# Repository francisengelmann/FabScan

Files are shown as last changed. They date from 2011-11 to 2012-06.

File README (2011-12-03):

FabScan - Affordable 3D Laser Scanning of Physical Objects

Visit http://hci.rwth-aachen.de/fabscan for presentation and documentation about the project.

FabScan makes use of the OpenCV and PCL (Point Cloud Library). See http://pointclouds.org/downloads/ for installation instructions.
For development on the Mac, just install Homebrew (http://mxcl.github.com/homebrew/) and type 'brew install opencv'.

Folder Structure:

-> arduino :: contains the firmware for the Arduino inside the FabScanner
-> experimental
  -> pointclouds :: sample pointclouds created with the FabScan
  -> PCL :: contains example code from the Point Cloud Library
-> parts :: contains all the models for the hardware
-> sources :: source code of FabScan software

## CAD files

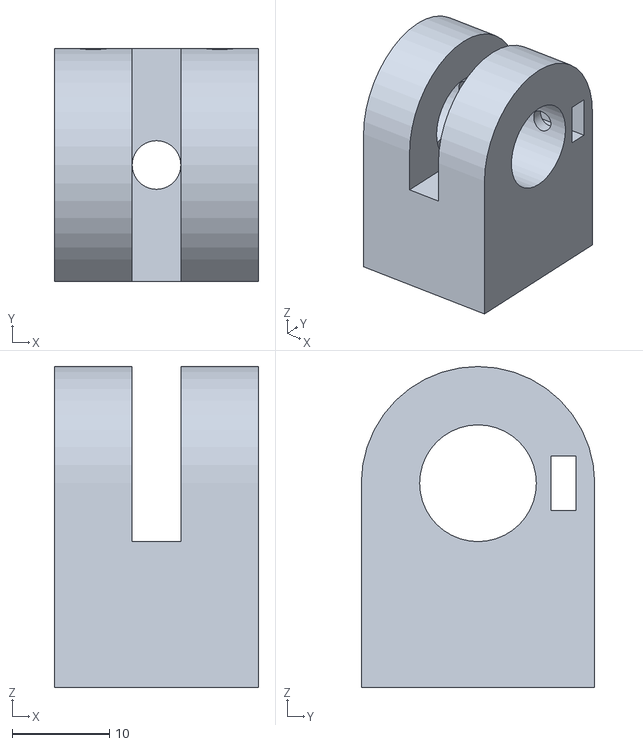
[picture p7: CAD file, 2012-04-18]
parts/LaserHolder2.stl
21.0 x 24.0 x 33.0

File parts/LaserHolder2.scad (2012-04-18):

$fn = 40; //change this to make the edges more round! Rendering will become slower.

lhIR = 6; //this is where you define the radius of your laser module!
lhOR = lhIR+6; 
lhH = 8;

shIR = 2.5;
shXS = shIR+2*lhH;
shYS = 2*lhOR;
shZS = 15;

nutY = 2.6;
nutZ = 5.6;

module screw(){
	rotate([-90,0,0])
	cylinder(h=25, r=1.5);
}

//breit: 5.4mm
//hoch: 2.3mm
module nut(){
	scale([25, nutY, nutZ])
	cube();
}

module laserHolder(){
	difference(){
		union(){
			rotate([0,90,0])
			cylinder(h=lhH, r=lhOR);
			translate([0,-lhOR,-(shZS+lhIR)])
			scale([lhH,2*lhOR,shZS+lhIR])
			cube(1);
		}
		rotate([0,90,0])
		translate([0,0,-1])
		cylinder(h=lhH+2, r=lhIR);
		translate([-2,(lhIR+lhOR)/2-1.5,-nutZ/2])
		nut();
		translate([lhH/2,0,0])
		screw();
	}
}

module stepperHolder(){
	difference(){
		translate([-shXS/2, -shYS/2])
		scale([shXS, shYS, shZS])
		cube(1);
		translate([0,0,-1])
		cylinder(h=shZS+2, r=shIR);	
	}
}

module complete(){
	difference(){
		union(){
			translate([0,0,lhIR+shZS]){
				translate([-lhH-shIR,0,0])
				laserHolder();
				translate([shIR,0,0])
				laserHolder();
			}
			stepperHolder();
		}
		rotate([0,0,90])
		translate([0,0,5])
		screw();
		rotate([90,90,0])
		translate([-3*nutZ,-7.5,-nutZ/2])
		nut();
	}
}

//laserHolder();
//stepperHolder();
complete();

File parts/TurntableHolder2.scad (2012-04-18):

$fn = 40;

r_motorSchaft = 2.5;
l_motorSchaft = 21;

r_aussparung = 10;
l_aussparung = 8;

r_Stange = 7.85/2;
l_Stange = 22.5;


//Schlitz 5.4 x 2.5

d_teller = 40;

dist_schrauben = d_teller/2;


module anMotor()
{
	difference()
	{
		cylinder( h=l_aussparung, r=r_aussparung);
		translate(v=[0,0,-1]) cylinder(h=l_motorSchaft, r=r_motorSchaft);
		translate(v=[-r_aussparung-0.5,0,4.8]) rotate(a=[0,90,0]) cylinder(h=r_aussparung*2+1, r=1.5);

		translate(v=[-r_aussparung+3.5,0-5.4/2,6+5.4/2]) rotate(a=[0,90,0]) scale([9.2, 5.4, 2.5]) cube(1);//Mutter
		translate(v=[r_aussparung-6,0-5.4/2,6+5.4/2]) rotate(a=[0,90,0]) scale([9.2, 5.4, 2.5]) cube(1);//Mutter



	}
}


module M3Schraube()
{
	translate([0,0,-3])
	{
		union()
		{
			cylinder(h=l_aussparung+9, r=1.5);

			//translate([0,0,l_aussparung+9]) cylinder(h=3.3, r=5.5/2);//dickerer Kopf für Senke
			translate([0,0,l_aussparung+9])  cylinder(h=l_aussparung+9, r=1.5);//da wir erstmal nur kleben wollen sparen wir hier stützmaterial
		}
	}

}

module rundung()
{
		union()
		{
		for ( i = [0 : 90] )
		{
			translate([0,0,l_aussparung+ i*0.1]) cylinder(h=0.1, r=r_aussparung + 2* sin(i)*d_teller/4);
		}
		}
}

module anStange()
{
	difference()
	{
		rundung();

		union()
		{
			translate(v=[0,0,-1]) cylinder(h=l_motorSchaft, r=r_motorSchaft);
			translate([dist_schrauben, 0, 0]){ M3Schraube(); translate([-3.0,-3.0,6.0]) scale([6.0, 6.0, 6.0]) cube(1);}
			translate([-dist_schrauben, 0, 0]){ M3Schraube();translate([-3.0,-3.0,6.0]) scale([6.0, 6.0, 6.0]) cube(1);}
			translate([0, dist_schrauben, 0]){ M3Schraube();translate([-3.0,-3.0,6.0]) scale([6.0, 6.0, 6.0]) cube(1);}
			translate([0, -dist_schrauben, 0]){ M3Schraube();translate([-3.0,-3.0,6.0]) scale([6.0, 6.0, 6.0]) cube(1);}
		}

	}
}


module sparbox()
{
	translate([0,5,l_aussparung+4]) scale([8,16,15]) cube(1, center=true);
}

module materialsparen()
{
union()
{
translate([-10,10,0]) rotate(45)  sparbox();
translate([17,17,0]) rotate(135)  sparbox();
translate([17,-17,0]) rotate(45)  sparbox();
translate([-10,-10,0]) rotate(135)  sparbox();
}
}


module kupplung()
{
	union()
	{
		anMotor();
		anStange();
	}
}

difference()
{
kupplung();
materialsparen();
}

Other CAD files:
experimental/pointclouds/whiteCup2/whiteCup.ply

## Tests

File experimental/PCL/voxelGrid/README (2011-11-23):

Downsampling a PointCloud using a VoxelGrid filter
==================================================
see http://pointclouds.org/documentation/tutorials/voxel_grid.php

Compiling the example
=====================
To compile and run the code, follow these steps:

mkdir build
cd build
cmake ..

Now the mafile should be there. Type this:

make
./voxel_grid

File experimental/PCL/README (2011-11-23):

Make sure you have cmake installed.

Installing PCL
==============
Linux:
	see http://pointclouds.org/downloads/linux.html

Mac: download and install Homebrew (http://mxcl.github.com/homebrew/)
	In Terminal type: brew install pcl

For more detailed information please check: http://pointclouds.org/downloads/

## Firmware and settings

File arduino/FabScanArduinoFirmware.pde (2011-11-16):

// FabScan - http://hci.rwth-aachen.de/fabscan
//
//  Created by Francis Engelmann on 7/1/11.
//  Copyright 2011 Media Computing Group, RWTH Aachen University. All rights reserved.

#define LED_PIN 14
#define LIGHT_PIN 11
#define LASER_PIN 5

#define ENABLE_PIN_0  6
#define RESET_PIN_0   7
#define SLEEP_PIN_0   8
#define STEP_PIN_0    9
#define DIR_PIN_0     10

#define ENABLE_PIN_1  3
#define RESET_PIN_1   2
#define SLEEP_PIN_1   4
#define STEP_PIN_1    13
#define DIR_PIN_1     12
  
#define TURN_LASER_OFF      200
#define TURN_LASER_ON       201
#define PERFORM_STEP        202
#define SET_DIRECTION_CW    203
#define SET_DIRECTION_CCW   204
#define TURN_STEPPER_ON     205
#define TURN_STEPPER_OFF    206
#define TURN_LIGHT_ON       207
#define TURN_LIGHT_OFF      208
#define ROTATE_LASER        209
#define FABSCAN_PING        210
#define FABSCAN_PONG        211
#define SELECT_STEPPER      212

//the protocol: we send one byte to define the action what to do.
//If the action is unary (like turnung off the light) we only need one byte so we are fine.
//If we want to tell the stepper to turn, a second byte is used to specify the number of steps.
//These second bytes are defined here below.

#define ACTION_BYTE         1    //normal byte, first of new action
#define LIGHT_INTENSITY     2
#define TURN_TABLE_STEPS    3
#define LASER1_STEPS        4
#define LASER2_STEPS        5
#define LASER_ROTATION      6
#define STEPPER_ID          7

int incomingByte = 0;
int byteType = 1;
int currStepper;

void step()
{
 digitalWrite(LED_PIN, 0);
 
 if(currStepper == 0){
   digitalWrite(STEP_PIN_0, 0);
 }else if(currStepper == 1){
   digitalWrite(STEP_PIN_1, 0);
 }

 delay(3);
 if(currStepper == 0){
   digitalWrite(STEP_PIN_0, 1);
 }else if(currStepper == 1){
   digitalWrite(STEP_PIN_1, 1);
 }
 digitalWrite(LED_PIN, 1);
 delay(3);
}

void step(int count)
{
  for(int i=0; i<count; i++){
    step();
  }
}

void setup() 
{ 
  // initialize the serial port
  Serial.begin(9600);
 pinMode(LASER_PIN, OUTPUT);
 pinMode(LIGHT_PIN, OUTPUT);
 pinMode(LED_PIN, OUTPUT);
 
 pinMode(ENABLE_PIN_1, OUTPUT);
 pinMode(RESET_PIN_1, OUTPUT);
 pinMode(SLEEP_PIN_1, OUTPUT);
 pinMode(DIR_PIN_1, OUTPUT);
 pinMode(STEP_PIN_1, OUTPUT);
 
 pinMode(ENABLE_PIN_0, OUTPUT);
 pinMode(RESET_PIN_0, OUTPUT);
 pinMode(SLEEP_PIN_0, OUTPUT);
 pinMode(DIR_PIN_0, OUTPUT);
 pinMode(STEP_PIN_0, OUTPUT);
  
 digitalWrite(RESET_PIN_0, HIGH);  //HIGH to turn
 digitalWrite(SLEEP_PIN_0, HIGH);  //HIGH to turn
 digitalWrite(ENABLE_PIN_0, HIGH);  //LOW to turn
  
 digitalWrite(RESET_PIN_1, HIGH);  //HIGH to turn
 digitalWrite(SLEEP_PIN_1, HIGH);  //HIGH to turn
 digitalWrite(ENABLE_PIN_1, HIGH);  //LOW to turn
 
 digitalWrite(LIGHT_PIN, 1); //turn light on

 digitalWrite(LASER_PIN, 1); //turn laser on
 Serial.write(FABSCAN_PONG); //send a pong back to the computer so we know setup is done and that we are actually dealing with a FabScan
 
 currStepper = 0;  //turntable is default stepper
} 

void loop() 
{
  digitalWrite(LED_PIN, 0);
  if(Serial.available() > 0){
    digitalWrite(LED_PIN, 1);
    incomingByte = Serial.read();
    
    switch(byteType){
      case ACTION_BYTE:
      
          switch(incomingByte){    //this switch always handles the first byte
            //Laser
            case TURN_LASER_OFF:
              digitalWrite(LASER_PIN, LOW);    // turn the LASER off
              break;
            case TURN_LASER_ON:
              digitalWrite(LASER_PIN, HIGH);   // turn the LASER on
              break;
            case ROTATE_LASER: //unused
              byteType = LASER_ROTATION;
              break;
            //TurnTable
            case PERFORM_STEP:
              byteType = TURN_TABLE_STEPS;
              break;
            case SET_DIRECTION_CW:
              if(currStepper == 0){
                digitalWrite(DIR_PIN_0, 1);
              }else if(currStepper == 1){
                digitalWrite(DIR_PIN_1, 1);
              }
              break;
            case SET_DIRECTION_CCW:
              if(currStepper == 0){
                digitalWrite(DIR_PIN_0, 0);
              }else if(currStepper == 1){
                digitalWrite(DIR_PIN_1, 0);
              }
              break;
            case TURN_STEPPER_ON:
              if(currStepper == 0){
                digitalWrite(ENABLE_PIN_0, 0);
              }else if(currStepper == 1){
                digitalWrite(ENABLE_PIN_1, 0);
              }
              break;
            case TURN_STEPPER_OFF:
              if(currStepper == 0){
                digitalWrite(ENABLE_PIN_0, 1);
              }else if(currStepper == 1){
                digitalWrite(ENABLE_PIN_1, 1);
              }
              break;
            case TURN_LIGHT_ON:
              byteType = LIGHT_INTENSITY;
              break;
            case TURN_LIGHT_OFF:
              digitalWrite(LIGHT_PIN, 0);
              break;
            case FABSCAN_PING:
              delay(1);
              Serial.write(FABSCAN_PONG);
              break;
            case SELECT_STEPPER:
              byteType = STEPPER_ID;
              break;
            }
      
          break;
       case LIGHT_INTENSITY:       //after this point we take care of the second byte if one is sent
          analogWrite(LIGHT_PIN, incomingByte);
          byteType = ACTION_BYTE;  //reset byteType
          break;
        case TURN_TABLE_STEPS:
          step(incomingByte);
          byteType = ACTION_BYTE;
          break;
        case STEPPER_ID:
          currStepper = incomingByte;
          byteType = ACTION_BYTE;
          break;
    }
  } 
} 

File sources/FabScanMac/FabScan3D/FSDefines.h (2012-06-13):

//
//  FSDefines.h
//  FabScan3D
//
//  Created by Francis Engelmann on 7/18/11.
//  Copyright 2011 Media Computing Group, RWTH Aachen University. All rights reserved.
//

//zero point of laser in model is perpendicular to the chessboard plane
//the offset_angle is the angle between the perpendicular and the actual laser line
#define LASER_OFFSET_ANGLE 0.0f
#define DELAY_UNTIL_CAM_SHOT 500000

//#define DPI_HORIZONTAL 10.0f
//#define DPI_VERTICAL 2.0f

/**
 * The following lines define the "protocol" for communication
 * between the computer and the microcontroller (MC) over the serial port.
 * Every byte stands for a operation.
 * All the values below 200 are reserved to position the servo, but servo sucks so this will be replaced and is not valid anymore
 * For 200-255 see below.
 */

#define MC_TURN_LASER_OFF      200
#define MC_TURN_LASER_ON       201
#define MC_PERFORM_STEP        202
#define MC_SET_DIRECTION_CW    203
#define MC_SET_DIRECTION_CCW   204
#define MC_TURN_STEPPER_ON     205
#define MC_TURN_STEPPER_OFF    206
#define MC_TURN_LIGHT_ON       207
#define MC_TURN_LIGHT_OFF      208
#define MC_ROTATE_LASER        209
#define MC_FABSCAN_PING        210
#define MC_FABSCAN_PONG        211
#define MC_SELECT_STEPPER      212

#define REALLY_BIG_NUMBER     99999
#define REALLY_SMALL_NUMBER  -99999

#define YES 1
#define NO  0

//treshold for substracting the laser frame from the non laser frame
#define TRESHOLD_FOR_BW 100 //70

#define STEPPER_ID_TURNTABLE  0
#define STEPPER_ID_LASER      1 

//to make the scanning process faster we ommit the lower and hight part of the cvImage
//as there is no object anyway.  The lower limit is defined by the turning table lower bound
//units are pixels, seen from the top, resp from the bottom

#define UPPER_ANALYZING_FRAME_LIMIT 250
#define LOWER_ANALYZING_FRAME_LIMIT 30

//as the actual position in the frame differs a little from calculated laserline we stop a little befor as we might catch the real non reflected laser line which creates noise
#define ANALYZING_LASER_OFFSET 100


//defining the origin in the cvFrame
//the position of intersection of back plane with ground plane in cvFrame in procent
//check the yellow laser line to calibrate, the yellow laser line should touch the bottom plane
//#define ORIGIN_Y 0.725
#define ORIGIN_Y 0.825

//the angle used to scan, obsolete when the laser is also moving
#define SCANNING_ANGLE 33.69f//33.69f

//filter to remove the points below this value, used to get rid of points from the turntable surface
#define MIN_Y_COORD 0.3f

//position of laser and cam
/*#define LASER_POS_X 14.0f
#define LASER_POS_Y 5.4f
#define LASER_POS_Z 26.9f

#define CAM_POS_X -0.5f
#define CAM_POS_Y 5.06f
#define CAM_POS_Z 24.2f
*/

// CAMERA DEFINES //

//33.2cm is the width of what the camera sees, ie place a measure tool at the back-plane and see how many cm the camera sees.

//logitech quickcam pro 9000
//#define FRAME_WIDTH 32.3f
//#define CAM_IMAGE_WIDTH 1600
//#define CAM_IMAGE_HEIGHT 1200

//logitech c920
//#define FRAME_WIDTH 35.0f 
//#define CAM_IMAGE_WIDTH 1920.0f
//#define CAM_IMAGE_HEIGHT 1080.0f

//logitech c270
#define FRAME_WIDTH 26.6f 
#define CAM_IMAGE_WIDTH 1280.0f
#define CAM_IMAGE_HEIGHT 853.0f


/* The axes of the orthogonal coordinate system are defined as follows:
  x-axe:  along the intersection of the middle plane and the back plane
          pointing to the right
  y-axe:  perpendiculare to the x-axe contained in the back plane
          pointing to the top
  z-axe:  perpendiculare to the x-axe contained in the middle plane, crossing the middle of the turntable
          pointing to the front
          
  The origin is the intersection of the three axes.
*/

//position of laser module
#define LASER_POS_X 14.0f //precise by construction
#define LASER_POS_Y 6.4f  //not needed/used for calculations
#define LASER_POS_Z 28.5f //precise by construction

//position of the quickcam 9000
//#define CAM_POS_X -0.7f
//#define CAM_POS_Y 5.3f //
//#define CAM_POS_Z 27.0f

//position of the c270
#define CAM_POS_X 0.0f
#define CAM_POS_Y 5.1257f //precise by construction 
#define CAM_POS_Y 4.07f //precise by construction 
#define CAM_POS_Z 30.7f

//position of the //c920 (these values are not exactly precise and should be determined by this software using algos like Eight-point algorithm)
//#define CAM_POS_X 0.0f
//#define CAM_POS_Y 6.3f 
//#define CAM_POS_Z 27.0f

//position of the turntable
#define TURNTABLE_POS_X 0.0f //not used by calculations
#define TURNTABLE_POS_Y 0.0f //not used by calculations
#define TURNTABLE_POS_Z 7.5f //precise by construction

//how big is the step the laser moves when pressing the button in the ctrl window
//#define LASER_STEP 33.69f
#define LASER_STEP 34.69f

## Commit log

2011-11-16 added arduino firmware
2011-12-02 Added Laser Holder .stl
    [LaserHolder.stl]
2012-04-18 added point cloud from a white coffee cup
    [whiteCup.ply]
2012-04-18 FabScan now uses the Logitech c920
    [LaserHolder.stl]
2012-04-18 added 3d printer parts, laser holder and turntable holder
    [LaserHolder2.scad, LaserHolder2.stl, TurntableHolder2.scad]
